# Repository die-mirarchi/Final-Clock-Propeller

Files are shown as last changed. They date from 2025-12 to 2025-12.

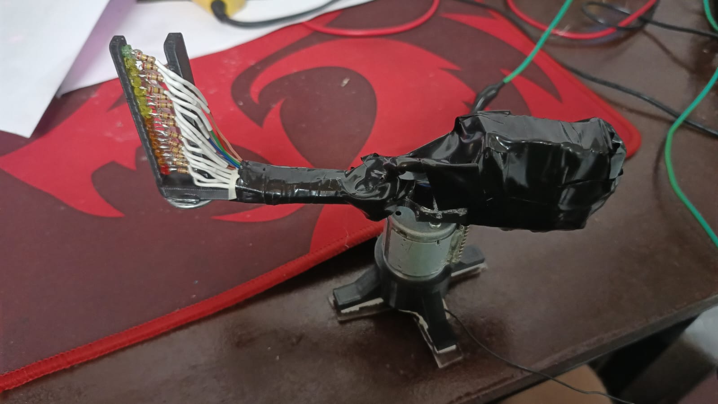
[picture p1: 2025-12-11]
docs/videos/photo1.jpeg

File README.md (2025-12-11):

# Digital Propeller 

## Descripción

Trabajo final para la materia **Digitales 2** de la **UNSAM** (Universidad Nacional de San Martín).  
**Año:** 2025 - Segundo Cuatrimestre  
**Autor:** Diego H. Mirarchi

Este proyecto implementa un digital propeller basado en el efecto de persistencia de visión (POV). Utiliza una barra vertical de 14 LEDs que, al girar, proyecta imágenes y texto en el aire mediante la sincronización precisa del encendido de los LEDs con la posición angular de rotación.

## Características Técnicas

- **Microcontrolador:** STM32F103 (Blue Pill)
- **LEDs:** 14 LEDs verticales controlados por GPIOA
- **Sincronización:** Detección por sensor hall SS49e con ADC de referencia en cada vuelta
- **Resolución angular:** 180 columnas por rotación completa (2° por columna)
- **Timer:** TIM2 configurado a 30 kHz para timestamping de rotación

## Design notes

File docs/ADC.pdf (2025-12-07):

# ADC - Analog to Digital Converter (Conversor Analógico Digital)

# Electrónica Digital II

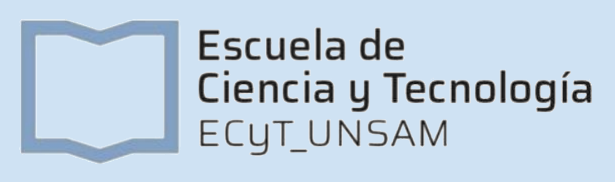
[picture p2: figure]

# ADC - Analog to Digital Converter

## ADC

## - Conversor de aproximaciones sucesivas de 12 bits

## - Canales: hasta 18, multiplexados (16 señales externas y 2 internas)

## - Modo de conversión: simple, continuo, scan o discontinuo

## - Almacena el resultado en un registro de 16 bits (alineado a izquierda o derecha)

## - Generación de interrupción al finalizar una conversión

## - El reloj ADCCLK es sincrónico con el APB2 clock. No puede superar los 14 MHz

Electrónica Digital II - ECyT

# Aproximaciones sucesivas (SAR)

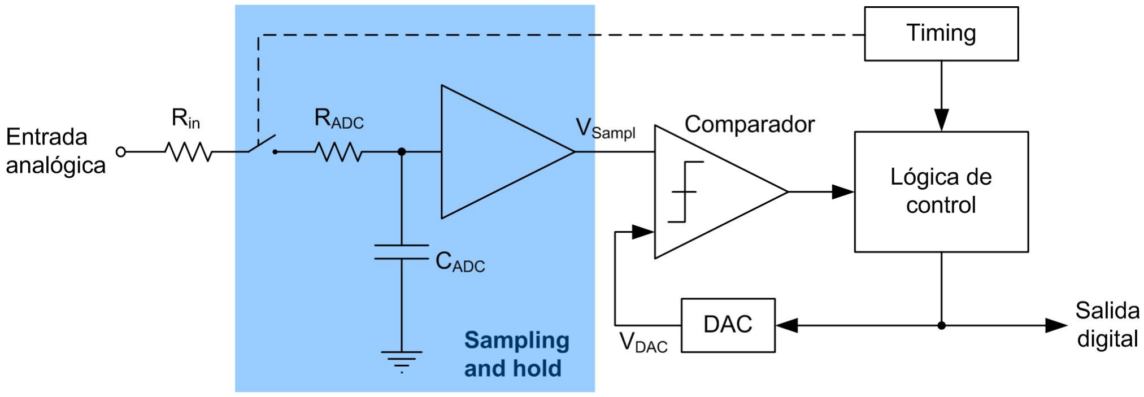
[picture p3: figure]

# Aproximaciones sucesivas (SAR)

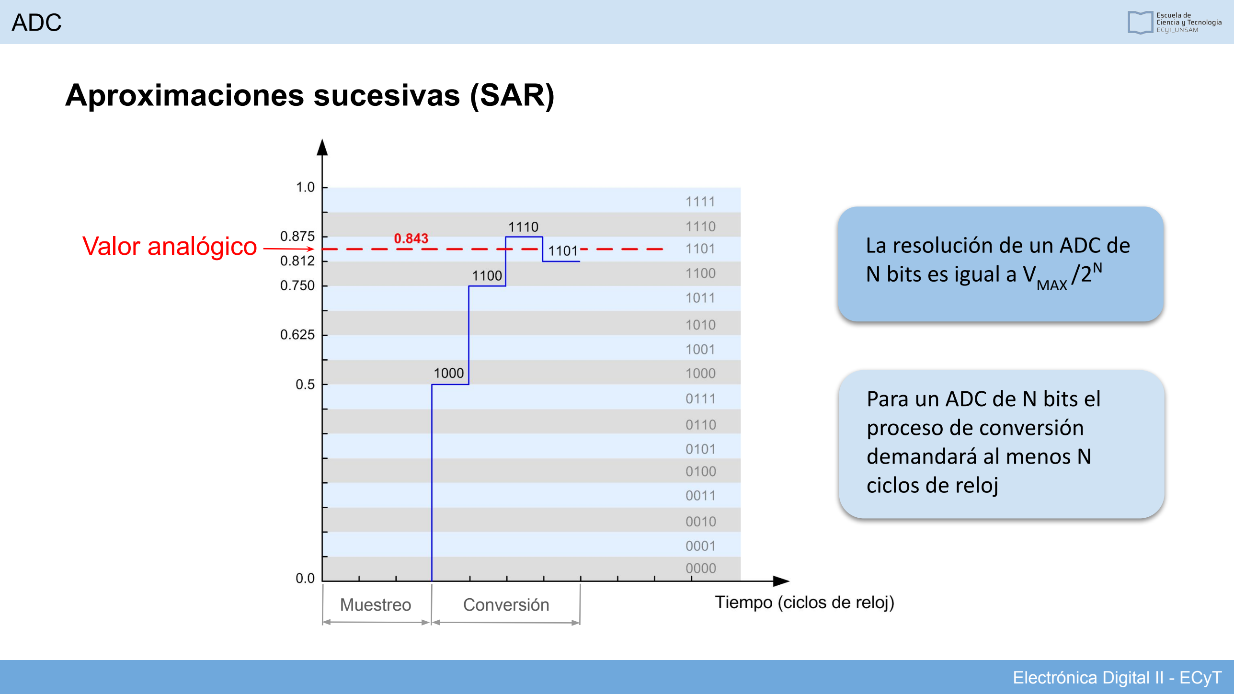
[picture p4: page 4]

Muestreo | Conversión

## La resolución de un ADC de N bits es igual a VMAX /2N

## Para un ADC de N bits el proceso de conversión demandará al menos N ciclos de reloj

## Valor analógico

# Tiempos de un ADC

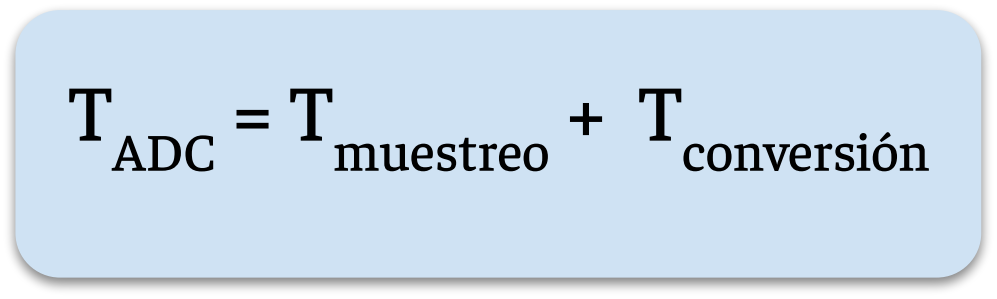
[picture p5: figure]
TADC = Tmuestreo + Tconversión

Suponiendo un ADC de 12 bits y tiempo de muestreo de 3 ciclos de reloj,

## con una frecuencia de operación de 10 MHz:

## TADC = Tmuestreo + Tconversión = 3 + 12 = 15 ciclos = 1.5 µs

# ADC - Analog to Digital Converter

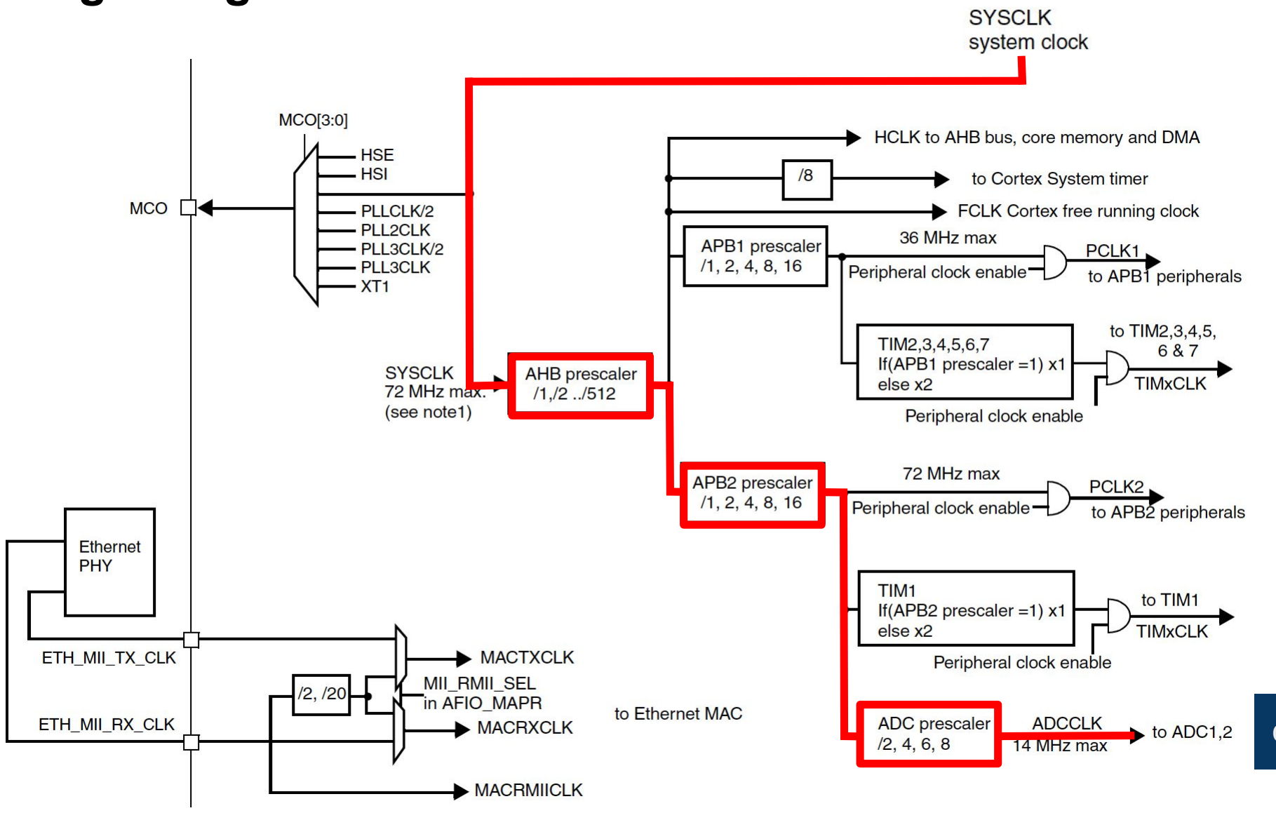
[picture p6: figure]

### clkADC ⩽ 14 MHz

# Selección de canal

## - Las conversiones pueden organizarse en dos grupos:

### - Compuesto por hasta 16 conversiones

### - Los canales regulares y su orden en la

### secuencia de conversión se seleccionan en el

### registro ADC_SQRx

### - La cantidad de conversiones debe ser escrita

### en los bits L[3:0] del registro ADC_SQR1

Grupo Regular | Grupo Inyectado

### - Compuesto por hasta 4 conversiones

### - Los canales inyectados y su orden en la

| secuencia de conversión se seleccionan en el registro ADC_JSQRx

### - La cantidad de conversiones debe ser escrita

| en los bits L[1:0] del registro ADC_JSQR

# Modo de conversión simple

## - El ADC sólo realiza una conversión

- La adquisición inicia colocando en ‘1’ el bit ADON en el registro ADC_CR2 (sólo para canal regular)

o por un trigger externo (para canal regular o inyectado).

## - Canal regular convertido:

## - El dato se guarda en el registro de 16 bits ADC_DR

- El flag EOC (End Of Conversion) se coloca en ‘1’ y la interrupción es generada si el bit

## EOCIE (EOC Interrupt Enable) está activo

## - Canal inyectado:

## - El dato se guarda en el registro de 16 bits ADC_DRJ1

- El flag JEOC (End Of Conversion Injected) se coloca en ‘1’ y la interrupción es generada si

## el bit JEOCIE está activo

## Finalmente el ADC se detiene

# Modo de conversión continua

## - El ADC inicia otra conversión apenas termina la actual

- La adquisición inicia colocando en ‘1’ el bit ADON en el registro ADC_CR2 (sólo para canal regular)

o por un trigger externo (para canal regular o inyectado).

## - Canal regular convertido:

## - El dato se guarda en el registro de 16 bits ADC_DR

- El flag EOC (End Of Conversion) se coloca en ‘1’ y la interrupción es generada si el bit

## EOCIE (EOC Interrupt Enable) está activo

## - Canal inyectado:

## - El dato se guarda en el registro de 16 bits ADC_DRJ1

- El flag JEOC (End Of Conversion Injected) se coloca en ‘1’ y la interrupción es generada si

## el bit JEOCIE está activo

# Modo Scan

## - Se adquiere un grupo de canales analógicos

- Se selecciona configurando el bit SCAN en el registro ADC_CR1.

## - Cuando se lo selecciona el ADC escanea todos los canales seleccionados en el registro

## ADC_SQRx (para canales regulares) o en el ADC_JSQR (para inyectados)

- Cada vez que finaliza una conversión continúa automáticamente con el siguiente canal del grupo.
- Al usar este modo el DMA debe estar activo ya que es usado para transferir los datos convertidos

de los canales de un grupo regular a la SRAM cada vez que se actualiza el registro ADC_DR.

- Los datos de los canales inyectados siempre se almacenan en los registro ADC_JDRx.

# Modos de operación

Canal único | Múltiples canales (Scan)

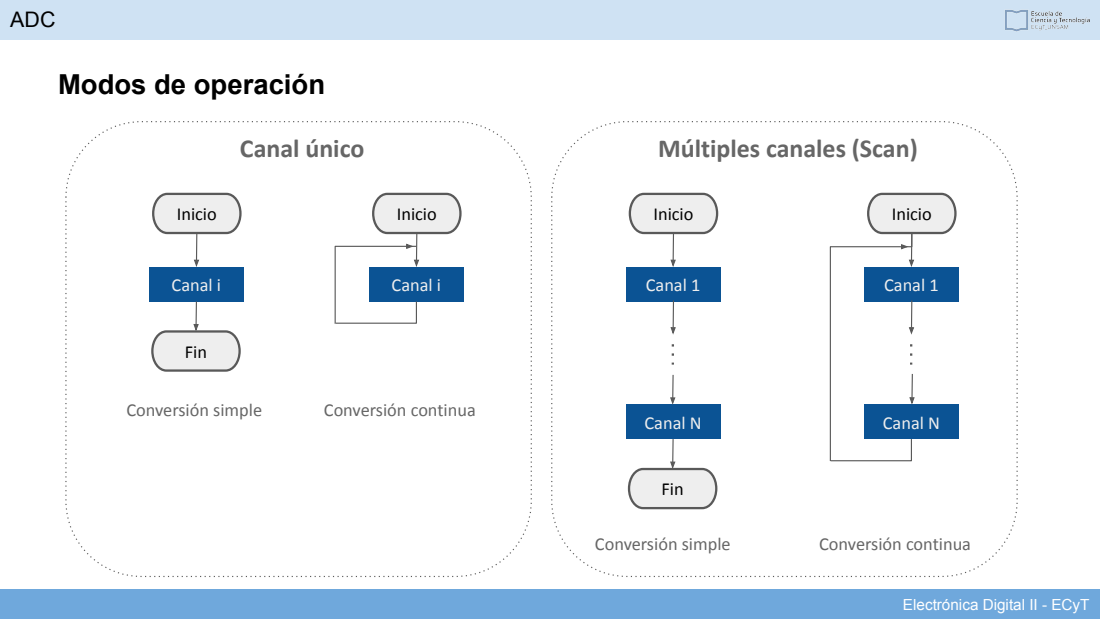
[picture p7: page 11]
Inicio; Fin; Canal i; Canal 1; Canal N; Conversión simple; Conversión continua

# Registros

## - Status Register (ADC_SR)

## - Control Register 1 / 2 (ADC_CR1 / ADC_CR2)

## - Sample Time Register 1 / 2 (ADC_SMPR1 / ADC_SMPR2)

## - Injected channel data offset register x (ADC_JOFRx) (x=1..4)

## - Regular sequence register 1 / 2 / 3 (ADC_SQR1 / ADC_SQR2 / ADC_SQR3)

## - Injected sequence register (ADC_JSQR)

## - Injected data register x (ADC_JDRx) (x= 1..4)

## - Regular data register (ADC_DR)

## - Watchdog high threshold register (ADC_HTR)

## - Watchdog low threshold register (ADC_LTR)

# ADC_SR (Registro de Estado)

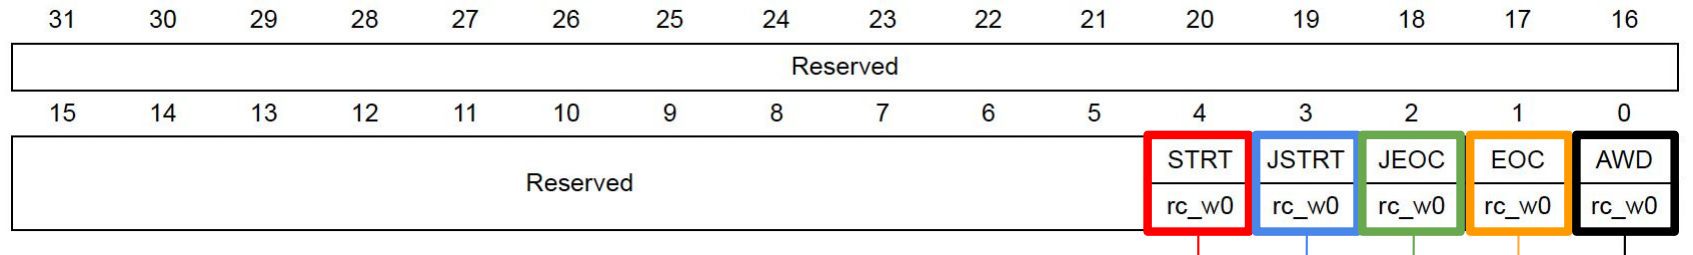
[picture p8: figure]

### Indica el inicio de la conversión de un canal regular

### Indica el inicio de la conversión de un grupo de canal inyectado

### Indica el final de la conversión de un canal inyectado

### Indica el final de la conversión (canal inyectado o regular)

### Indica si el valor convertido es mayor o menor a lo configurado

# ADC_CR1 (Registro de Control 1)

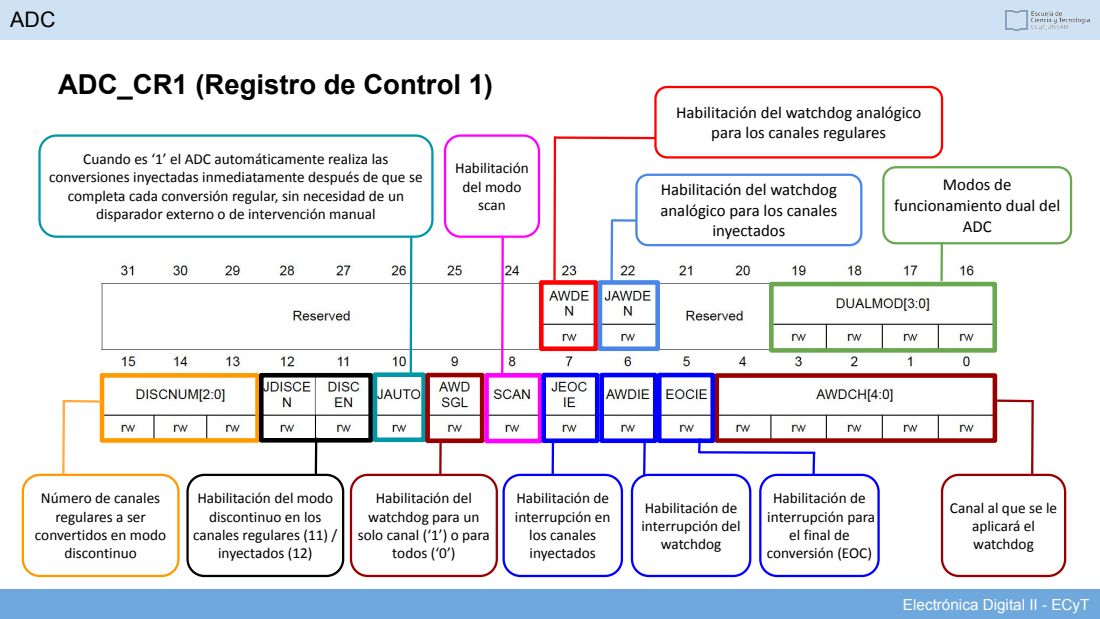
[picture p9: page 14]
inyectados; Modos de; ADC; Habilitación del modo scan; Habilitación de interrupción en los canales inyectados; Habilitación de interrupción del watchdog

Habilitación del watchdog analógico
para los canales regulares

Cuando es ‘1’ el ADC automáticamente realiza las
conversiones inyectadas inmediatamente después de que se
completa cada conversión regular, sin necesidad de un
disparador externo o de intervención manual

Habilitación del watchdog
analógico para los canales

funcionamiento dual del

Número de canales
regulares a ser
convertidos en modo
discontinuo

Habilitación del modo
discontinuo en los
canales regulares (11) /
inyectados (12)

Habilitación del
watchdog para un
solo canal (‘1’) o para
todos (‘0’)

Habilitación de
interrupción para
el final de
conversión (EOC)

Canal al que se le
aplicará el
watchdog

# ADC_CR2 (Registro de Control 2)

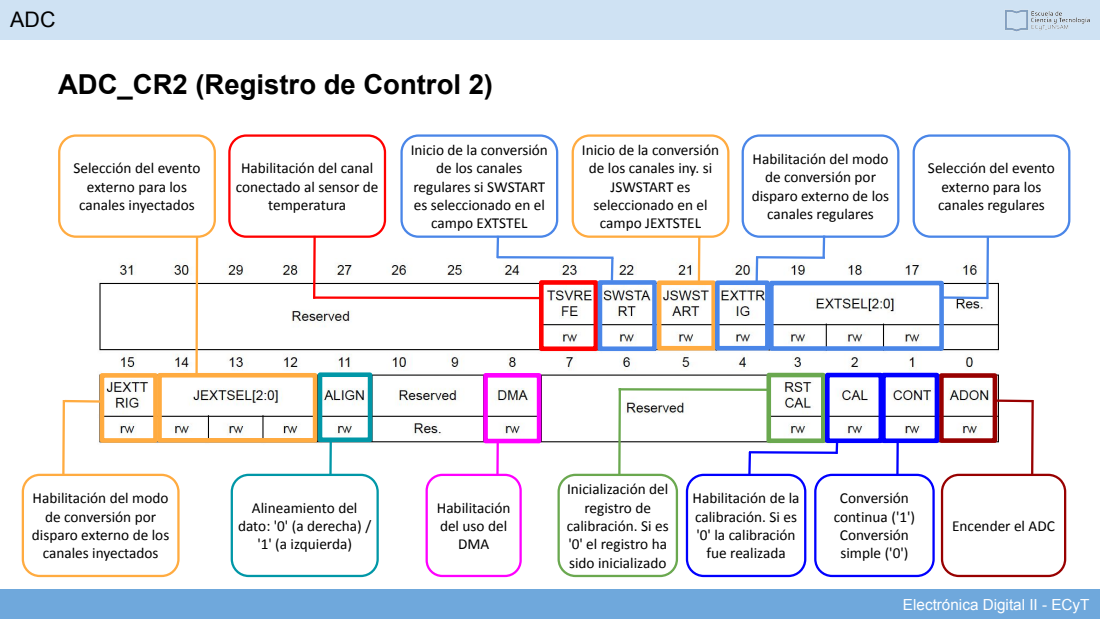
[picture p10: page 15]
Conversión continua ('1') Conversión simple ('0'); Alineamiento del dato: '0' (a derecha) / '1' (a izquierda)

Inicio de la conversión
de los canales
regulares si SWSTART
es seleccionado en el
campo EXTSTEL

de los canales iny. si
JSWSTART es
seleccionado en el
campo JEXTSTEL

Habilitación del modo
de conversión por
disparo externo de los
canales regulares

Selección del evento
externo para los
canales inyectados

Habilitación del canal
conectado al sensor de
temperatura

Inicialización del
registro de
calibración. Si es
'0' el registro ha
sido inicializado

Habilitación de la
'0' la calibración
fue realizada

Habilitación
del uso del
DMA

Encender el ADC

# ADC_SMPR1 (Registro de Tiempo de Muestreo 1)

## 000: 1.5 ciclos 100: 41.5 ciclos

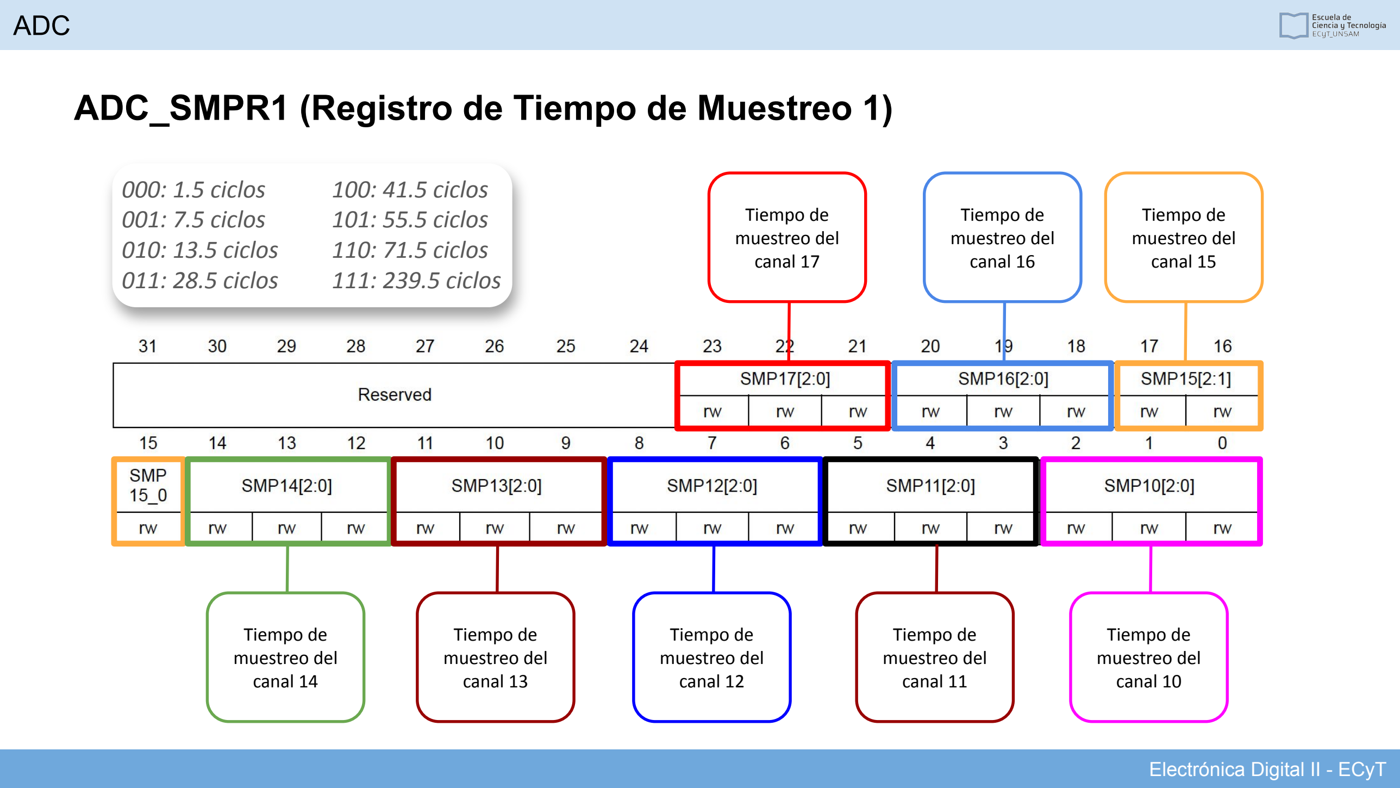
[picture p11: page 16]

Tiempo de
muestreo del
canal 13

Tiempo de
muestreo del
canal 12

Tiempo de
muestreo del
canal 11

Tiempo de
muestreo del
canal 10

Tiempo de
muestreo del
canal 14

Tiempo de
muestreo del
canal 17

Tiempo de
muestreo del
canal 16

Tiempo de
muestreo del
canal 15
001: 7.5 ciclos | 101: 55.5 ciclos
010: 13.5 ciclos | 110: 71.5 ciclos
011: 28.5 ciclos | 111: 239.5 ciclos

# ADC_SMPR2 (Registro de Tiempo de Muestreo 2)

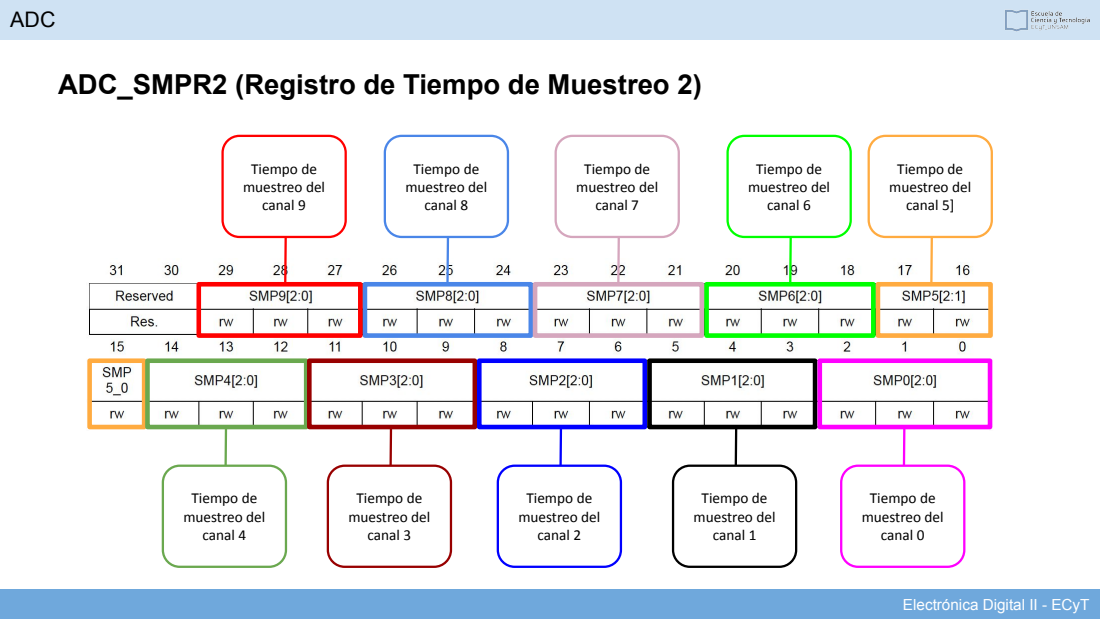
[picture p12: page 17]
Tiempo de muestreo del canal 3; Tiempo de muestreo del canal 2; Tiempo de muestreo del canal 1; Tiempo de muestreo del canal 0; Tiempo de muestreo del canal 4; Tiempo de muestreo del canal 9; Tiempo de muestreo del canal 8; Tiempo de muestreo del canal 5]; Tiempo de muestreo del canal 7; Tiempo de muestreo del canal 6

# ADC_JOFRx (Registro de Offset de dato de canal inyectado)

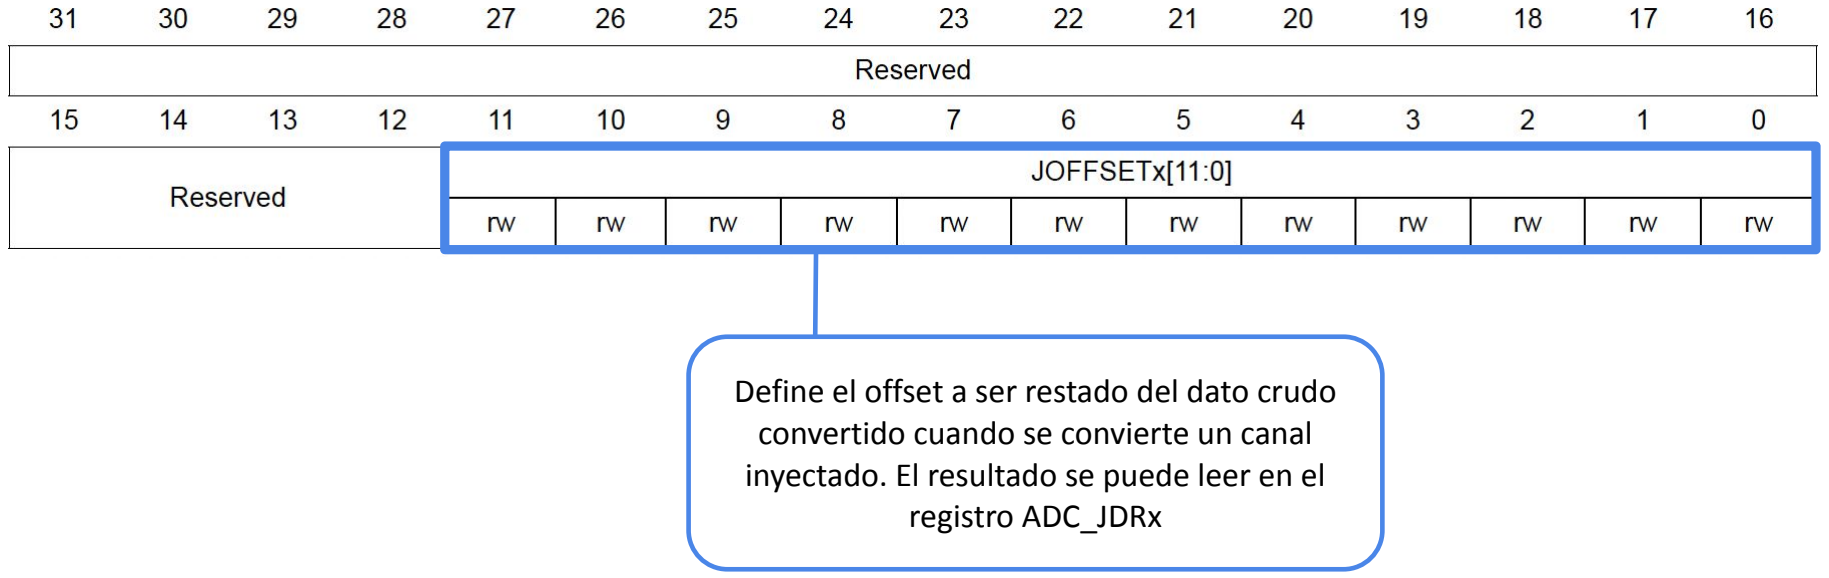
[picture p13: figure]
convertido cuando se convierte un canal; registro ADC_JDRx

Define el offset a ser restado del dato crudo

inyectado. El resultado se puede leer en el

# ADC_HTR (Registro para el umbral alto del watchdog)

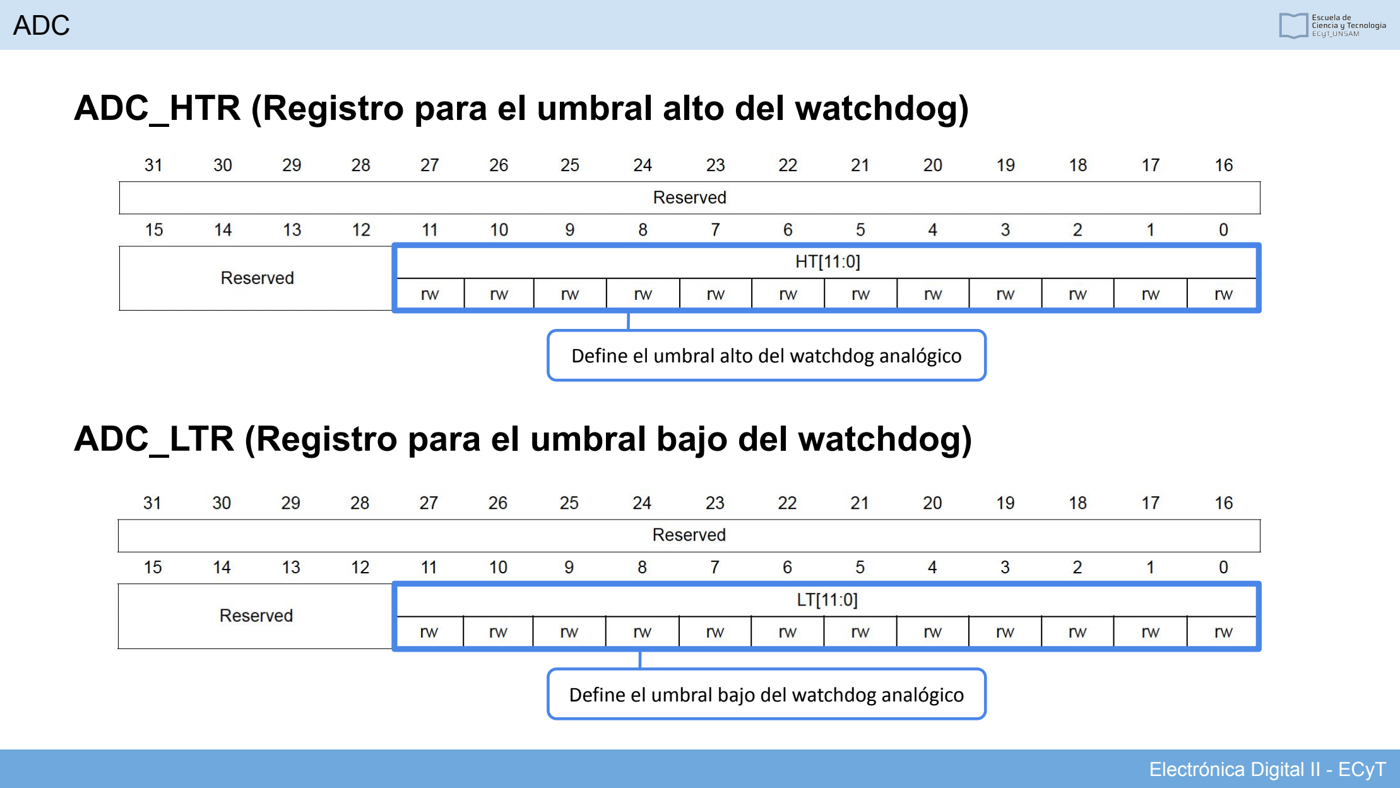
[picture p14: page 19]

Define el umbral alto del watchdog analógico

# ADC_LTR (Registro para el umbral bajo del watchdog)

Define el umbral bajo del watchdog analógico

# ADC_SQR1 (Registro de secuencia de los canales regulares 1)

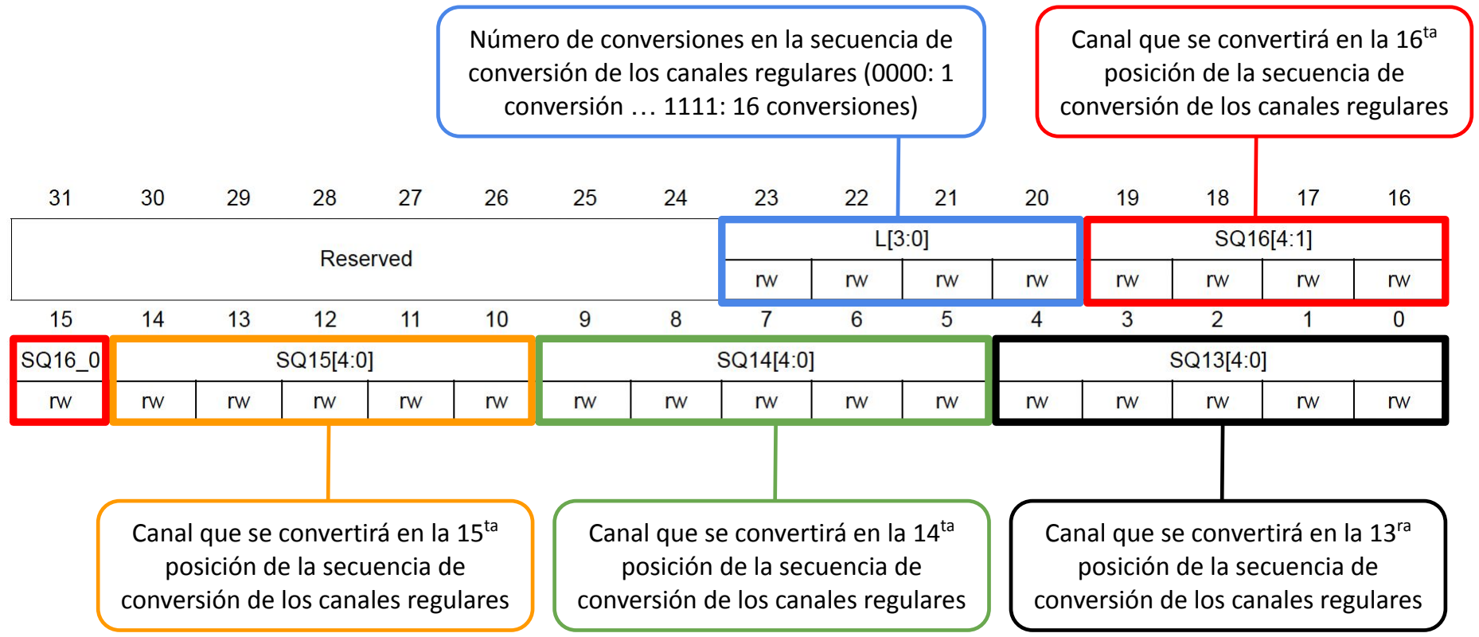
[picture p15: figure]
conversión … 1111: 16 conversiones); Canal que se convertirá en la 16ta posición de la secuencia de conversión de los canales regulares; Canal que se convertirá en la 15ta posición de la secuencia de conversión de los canales regulares; Canal que se convertirá en la 14ta posición de la secuencia de conversión de los canales regulares; Canal que se convertirá en la 13ra posición de la secuencia de conversión de los canales regulares

Número de conversiones en la secuencia de conversión de los canales regulares (0000: 1

# ADC_SQR2 (Registro de secuencia de los canales regulares 2)

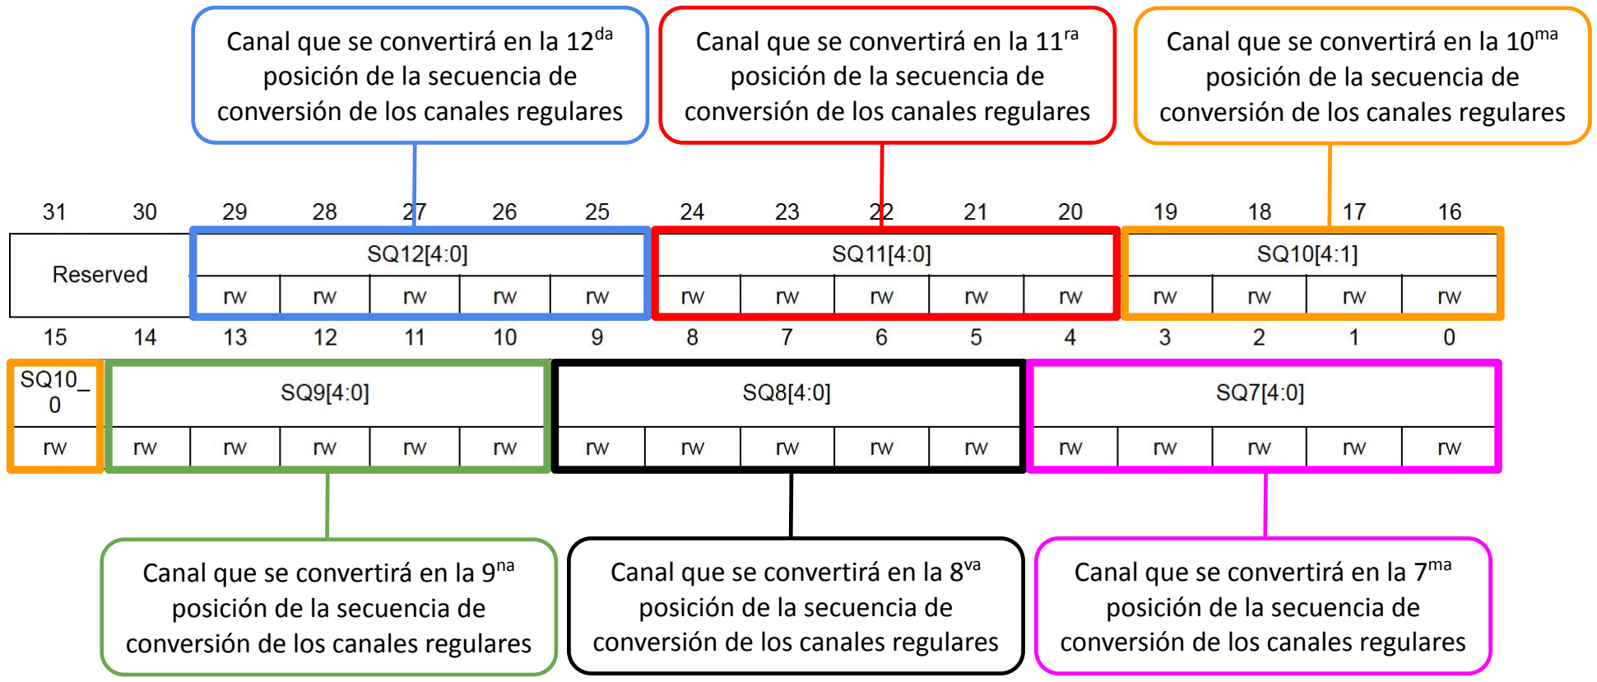
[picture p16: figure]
Canal que se convertirá en la 11ra posición de la secuencia de conversión de los canales regulares; Canal que se convertirá en la 10ma posición de la secuencia de conversión de los canales regulares; Canal que se convertirá en la 9na posición de la secuencia de conversión de los canales regulares; Canal que se convertirá en la 8va posición de la secuencia de conversión de los canales regulares; Canal que se convertirá en la 12da posición de la secuencia de conversión de los canales regulares; Canal que se convertirá en la 7ma posición de la secuencia de conversión de los canales regulares

# ADC_SQR3 (Registro de secuencia de los canales regulares 3)

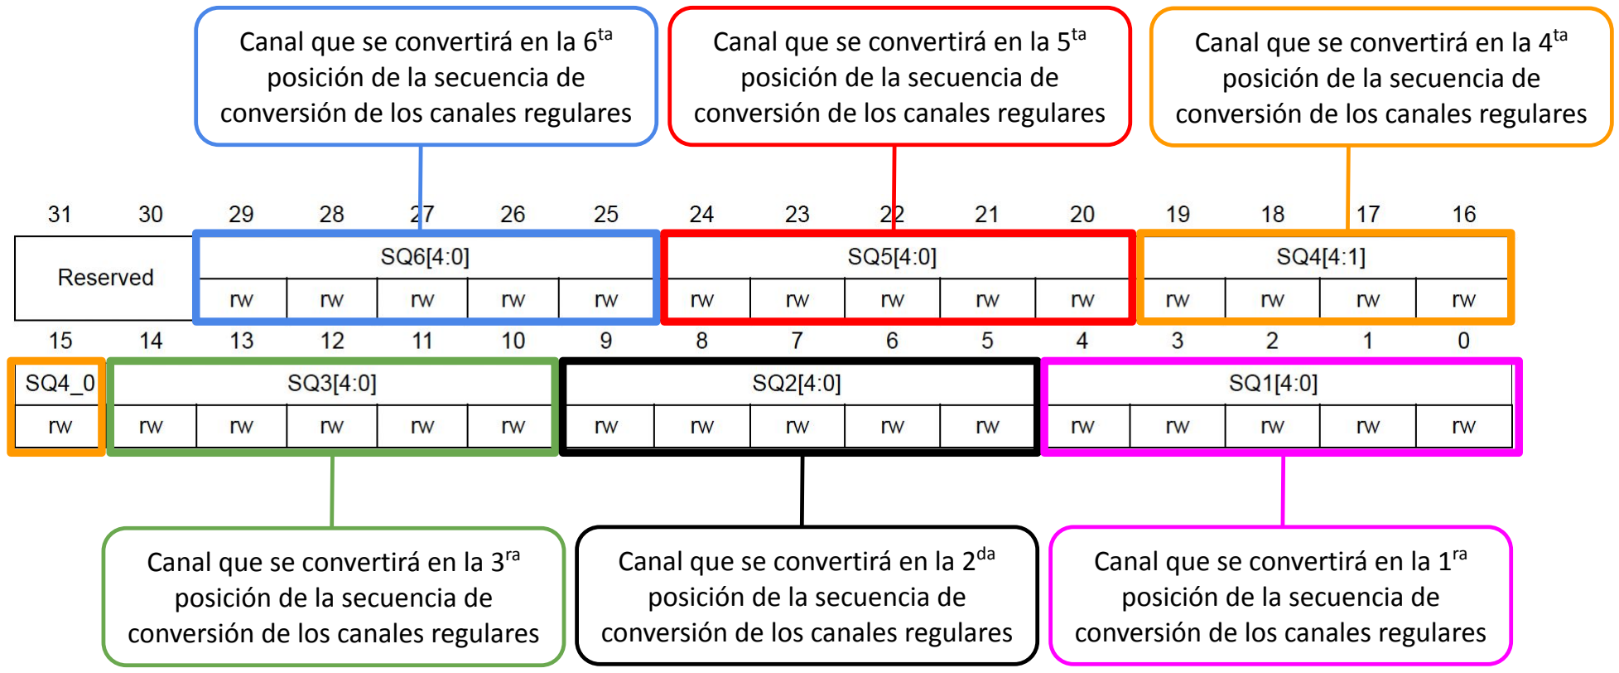
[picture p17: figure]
Canal que se convertirá en la 5ta posición de la secuencia de conversión de los canales regulares; Canal que se convertirá en la 4ta posición de la secuencia de conversión de los canales regulares; Canal que se convertirá en la 3ra posición de la secuencia de conversión de los canales regulares; Canal que se convertirá en la 2da posición de la secuencia de conversión de los canales regulares; Canal que se convertirá en la 6ta posición de la secuencia de conversión de los canales regulares; Canal que se convertirá en la 1ra posición de la secuencia de conversión de los canales regulares

# ADC_JSQR (Registro de secuencia de los canales inyectados)

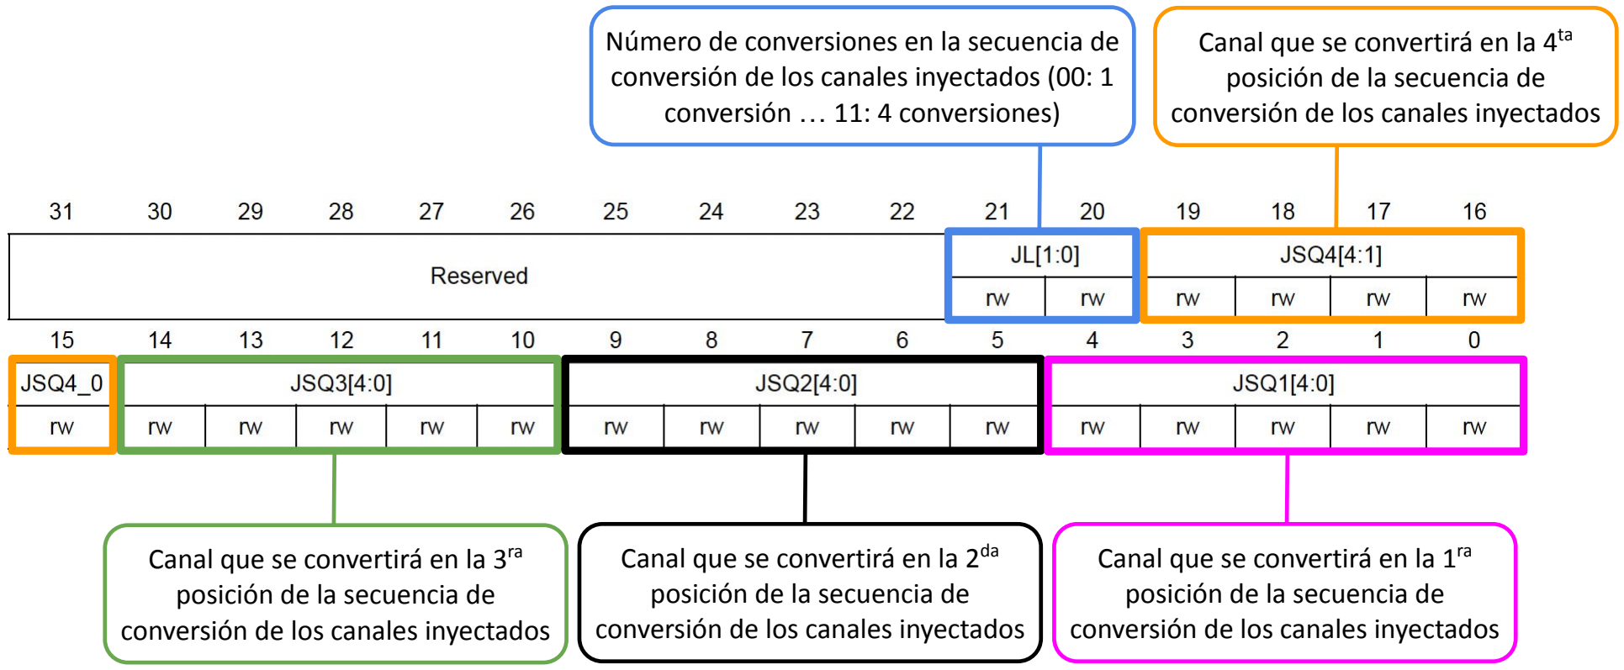
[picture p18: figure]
Canal que se convertirá en la 4ta posición de la secuencia de conversión de los canales inyectados; Canal que se convertirá en la 3ra posición de la secuencia de conversión de los canales inyectados; Canal que se convertirá en la 2da posición de la secuencia de conversión de los canales inyectados; conversión … 11: 4 conversiones); Canal que se convertirá en la 1ra posición de la secuencia de conversión de los canales inyectados

Número de conversiones en la secuencia de conversión de los canales inyectados (00: 1

# ADC_JSQR (Registro de secuencia de los canales inyectados)

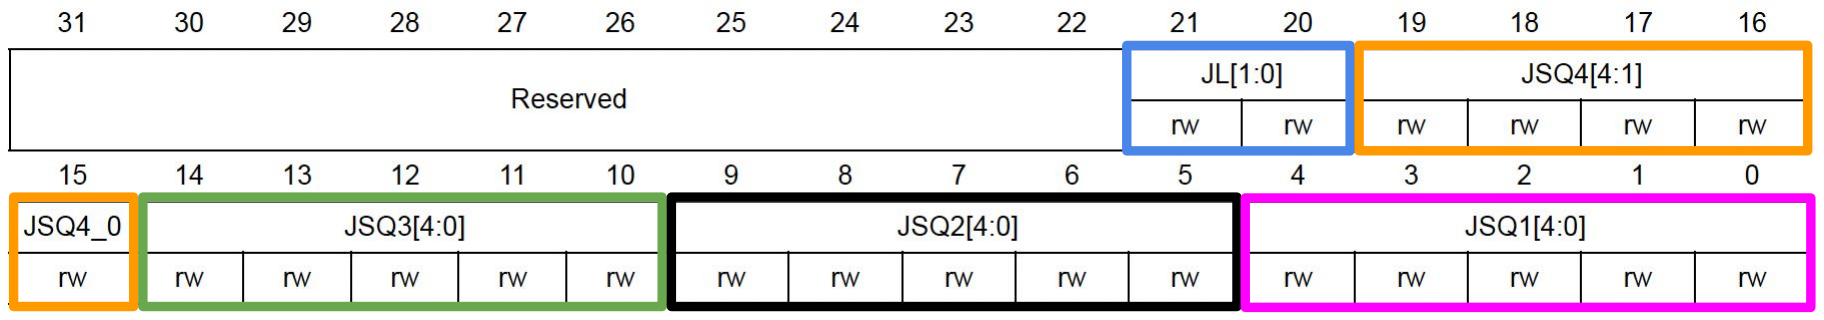
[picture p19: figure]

Cuando JL=3 (4 conversiones en la secuencia), el ADC convierte los canales en el orden: JSQ1[4:0] → JSQ2[4:0] → JSQ3[4:0] → JSQ4[4:0]

Cuando JL=2 (3 conversiones en la secuencia), el ADC convierte los canales en el orden: JSQ2[4:0] → JSQ3[4:0] → JSQ4[4:0]

Cuando JL=1 (2 conversiones en la secuencia), el ADC convierte los canales en el orden: JSQ3[4:0] → JSQ4[4:0]

Cuando JL=0 (1 conversión en la secuencia), el ADC convierte sólo el canal JSQ4[4:0]

# ADC_JDRx (Registro de datos de los canales inyectados) (x = 1..4)

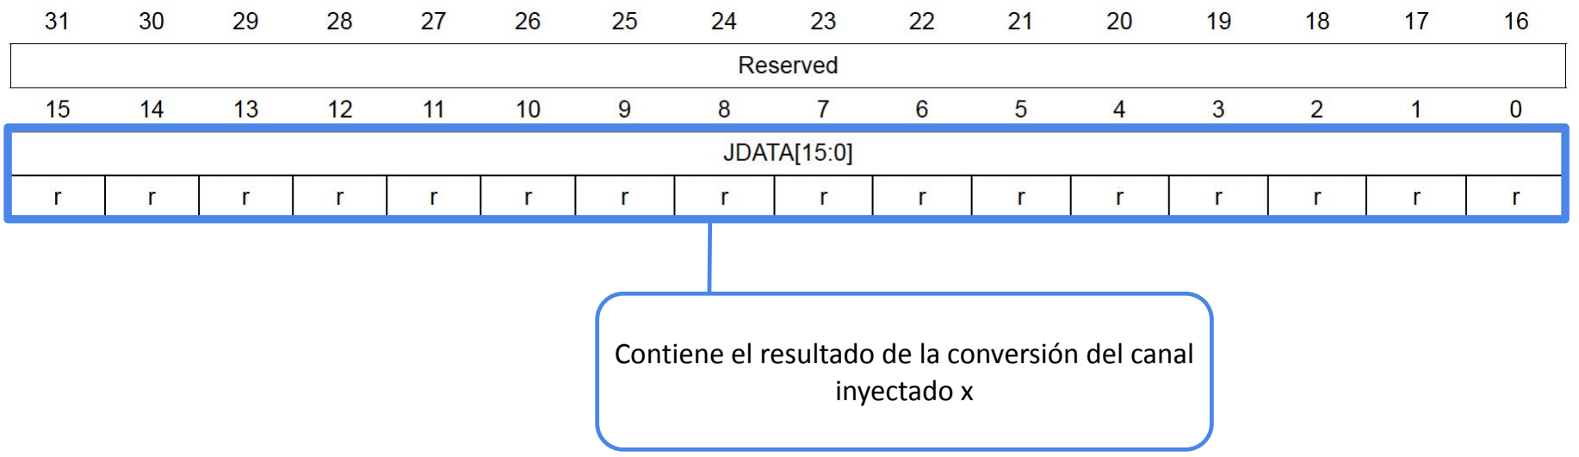
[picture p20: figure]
inyectado x

Contiene el resultado de la conversión del canal

# ADC_DR (Registro de datos de los canales regulares)

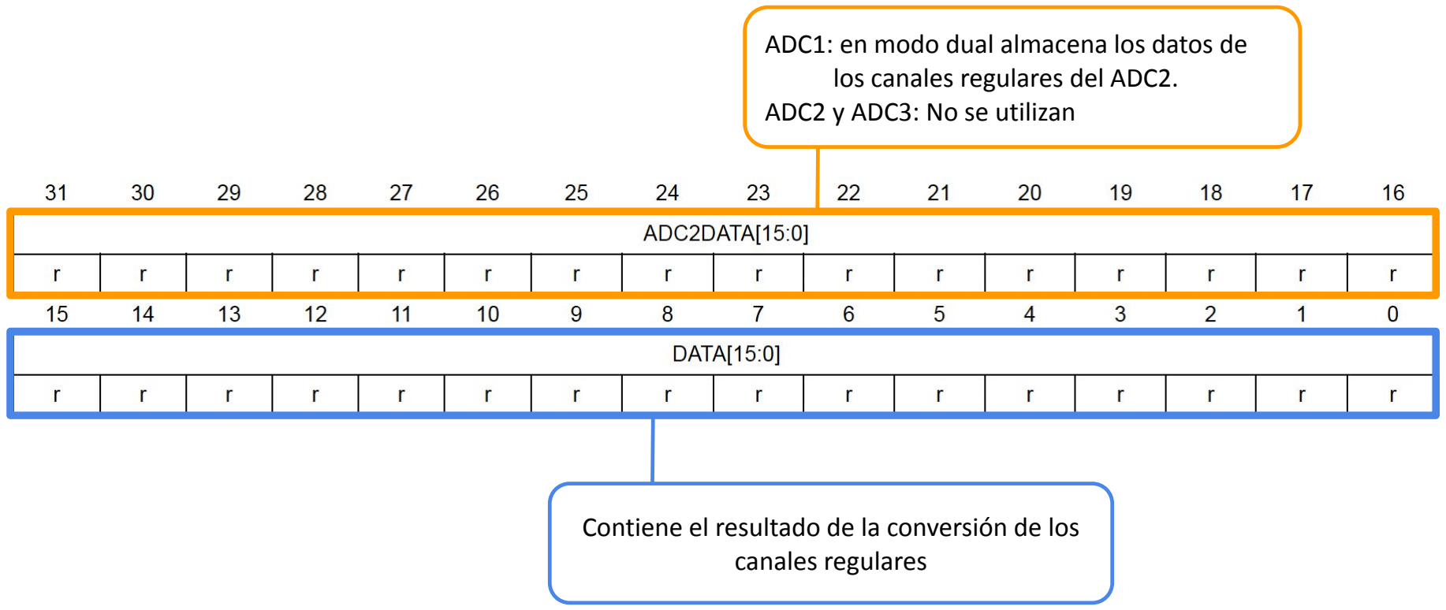
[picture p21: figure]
canales regulares; los canales regulares del ADC2. ADC2 y ADC3: No se utilizan

Contiene el resultado de la conversión de los

ADC1: en modo dual almacena los datos de

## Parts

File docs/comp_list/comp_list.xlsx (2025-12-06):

Componente | Cantidad
ULN2003 | 2
Leds | 14
BluePill | 1
Resistor | 14
Bateria 3.7V | 1
A3144 | 1
TP4056 | 1
Step-Up DC DC | 1
Motor DC | 1
Iman | 1

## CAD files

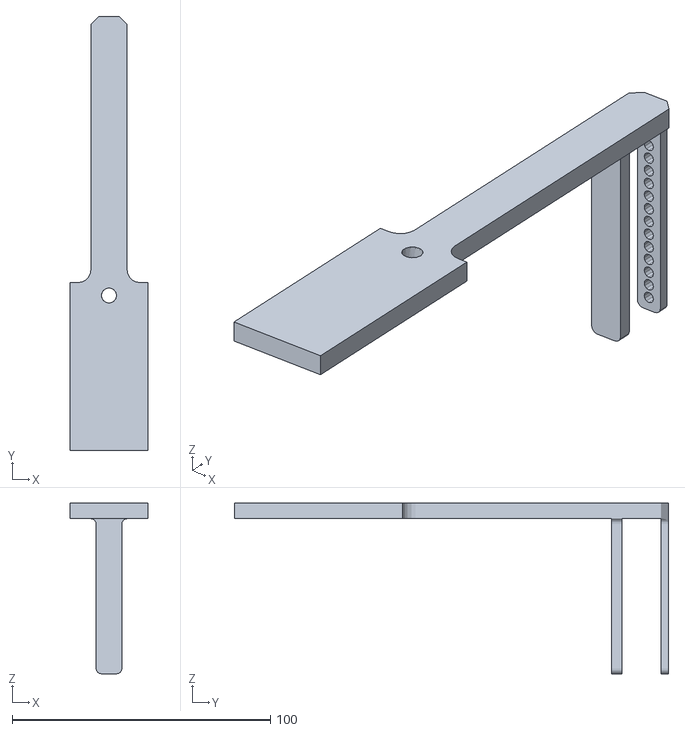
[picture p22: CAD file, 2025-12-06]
3d/leds_holder.stl
30.0 x 168.0 x 66.0

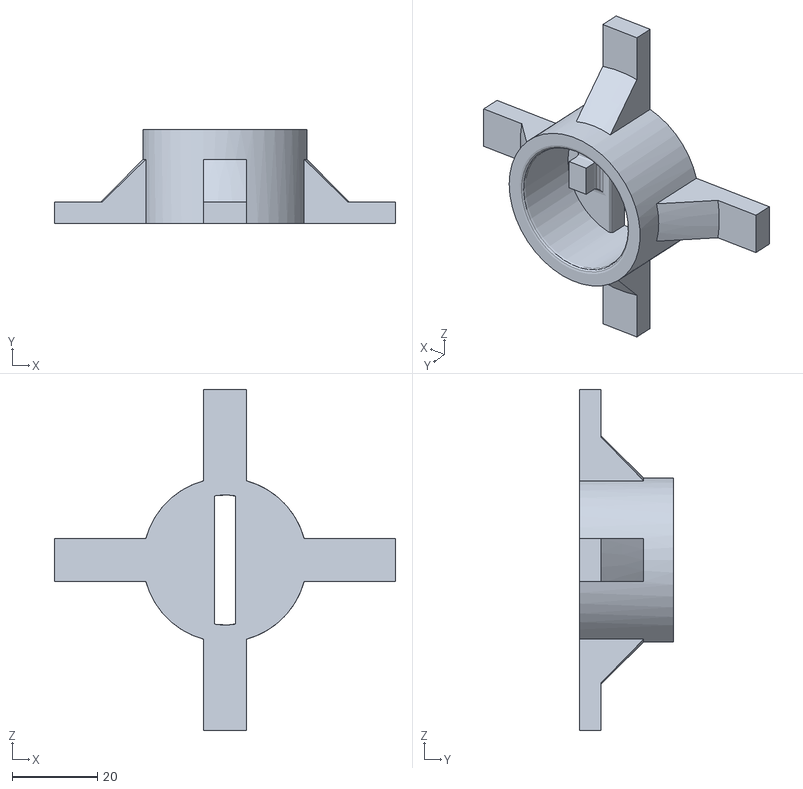
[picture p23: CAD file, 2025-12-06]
3d/motor_holder.stl
80.0 x 22.0 x 80.0

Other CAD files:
3d/OldVersions/leds_holder.0002.ipt
3d/Part1.ipt
3d/cnc_wood_holder.ipt
3d/leds_holder - copia.ipt
3d/leds_holder.ipt

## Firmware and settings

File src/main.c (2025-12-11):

#define SRAM_SIZE		((uint32_t) 0x00005000)
#define SRAM_BASE		((uint32_t) 0x20000000)
#define STACKINIT		((interrupt_t)(SRAM_BASE+SRAM_SIZE))

typedef int			   int32_t;
typedef short		   int16_t;
typedef char		   int8_t;
typedef unsigned int   uint32_t;
typedef unsigned short uint16_t;
typedef unsigned char  uint8_t;
typedef unsigned long long uint64_t;

typedef void(*interrupt_t)(void);

typedef union {
	uint8_t  byte[4];
	uint16_t hword[2];
	uint32_t word;
} word_t;

typedef word_t page[0x400/sizeof(uint32_t)];

// Memory map

enum {TIM2	= 0, TIM3  = 1, TIM4  = 2 };
enum {GPIOA = 0, GPIOB = 1, GPIOC = 2, GPIOD = 3, GPIOE = 4, GPIOF = 5 };
enum {DMA1	= 0 };
enum {CHN1	= 0, CHN2  = 1, CHN3  = 2, CHN4  = 3, CHN5	= 4, CHN6  = 5, CHN7 = 6, CHN8 = 7 };
enum {ADC1	= 0 };
struct {
	union {
		struct {
			uint32_t CR1;
			uint32_t CR2;
			uint32_t SMCR;
			uint32_t DIER;
			uint32_t SR;
			uint32_t EGR;
			uint32_t CCMR1;
			uint32_t CCMR2;
			uint32_t CCER;
			uint32_t CNT;
			uint32_t PSC;
			uint32_t ARR;
			uint32_t RES1;
			uint32_t CCR1;
			uint32_t CCR2;
			uint32_t CCR3;
			uint32_t CCR4;
			uint32_t BDTR;
			uint32_t DCR;
			uint32_t DMAR;
		} REGs;
		page reserved;
	} TIMs[3];

	word_t reserved1[(0x40002800-0x40000c00)/sizeof(word_t)];
	page RTC;
	page WWDG;
	page IWDG;
	word_t reserved2[(0x40003800-0x40003400)/sizeof(word_t)];
	page SPI2;
	word_t reserved3[(0x40004400-0x40003c00)/sizeof(word_t)];
	page USART[2];
	word_t reserved4[(0x40005400-0x40004c00)/sizeof(word_t)];
	page I2C[2];
	page USB;
	page USBCAN_SRAM;
	page bxCAN;
	word_t reserved5[(0x40006c00-0x40006800)/sizeof(word_t)];
	page BKP;
	page PWR;
	word_t reserved6[(0x40010000-0x40007400)/sizeof(word_t)];

	page AFIO;
	page EXTI;

	union {
		struct {
			uint32_t CRL;
			uint32_t CRH;
			uint32_t IDR;
			uint32_t ODR;
			uint32_t BSRR;
			uint32_t BRR;
			uint32_t LCKR;
		} REGs;
		page reserved;
	} GPIOs[5];
	word_t reserved7[(0x40012400-0x40011C00)/sizeof(word_t)];
union {
    struct {
        uint32_t SR;
        uint32_t CR1;
        uint32_t CR2;
        uint32_t SMPR1;
        uint32_t SMPR2;
        uint32_t JOFR[4];   // JOFR1..4
        uint32_t HTR;
        uint32_t LTR;
        uint32_t SQR1;
        uint32_t SQR2;
        uint32_t SQR3;
        uint32_t JSQR;
        uint32_t JDR[4];    // JDR1..4
        uint32_t DR;
    } REGs;
    page reserved;
} ADC[2];
	page TIM1;
	page SPI1;
	word_t reserved8[(0x40013800-0x40013400)/sizeof(word_t)];
	union  {
		struct {
			uint32_t SR;
			uint32_t DR;
			uint32_t BRR;
			uint32_t CR1;
			uint32_t CR2;
			uint32_t CR3;
			uint32_t GTPR;
		} REGs;
		page reserved;
	} USART1;
	word_t reserved9[(0x40020000-0x40013C00)/sizeof(word_t)];
	union {
		struct {
			uint32_t ISR;
			uint32_t IFCR;
			struct {
				uint32_t CCR;
				uint32_t CNDTR;
				uint32_t CPAR;
				uint32_t CMAR;
				uint32_t RESERVED;
			} CHN[8];
		} REGs;
		page reserved;
	} DMAs[1];
	word_t reservedA[(0x40021000-0x40020400)/sizeof(word_t)];

	union {
		struct {
			uint32_t CR;
			uint32_t CFGR;
			uint32_t CIR;
			uint32_t APB2RSTR;
			uint32_t APB1RSTR;
			uint32_t AHBENR;
			uint32_t APB2ENR;
			uint32_t APB1ENR;
			uint32_t BDCR;
			uint32_t CSR;
			uint32_t AHBRSTR;
			uint32_t CFGR2;
		} REGs;
		page reserved;
	} RCC;
	word_t reservedB[(0x40022000-0x40021400)/sizeof(word_t)];

	union {
		struct {
			uint32_t ACR;
			uint32_t KEYR;
			uint32_t OPTKEYR;
			uint32_t SR;
			uint32_t CR;
			uint32_t AR;
			uint32_t reserved;
			uint32_t OBR;
			uint32_t WRPR;
		} REGs;
		page reserved;
	} FLASH;
} volatile *const DEVMAP = (void *) 0x40000000;

#define ENA_IRQ(IRQ) {CTX->NVIC.REGs.ISER[((uint32_t)(IRQ) >> 5)] = (1 << ((uint32_t)(IRQ) & 0x1F));}
#define DIS_IRQ(IRQ) {CTX->NVIC.REGs.ICER[((uint32_t)(IRQ) >> 5)] = (1 << ((uint32_t)(IRQ) & 0x1F));}
#define CLR_IRQ(IRQ) {CTX->NVIC.REGs.ICPR[((uint32_t)(IRQ) >> 5)] = (1 << ((uint32_t)(IRQ) & 0x1F));}

struct {
	word_t reversed0[(0xe000e010-0xe0000000)/sizeof(word_t)];
	union {
		struct {
			uint32_t CSR;
			uint32_t RVR;
			uint32_t CVR;
			uint32_t CALIB;
		} REGs;
	} SYSTICK;
	word_t reversed1[(0xe000e100-0xe000e020)/sizeof(word_t)];
	union {
		struct {
			uint32_t ISER[8];
			uint32_t RES0[24];
			uint32_t ICER[8];
			uint32_t RES1[24];
			uint32_t ISPR[8];
			uint32_t RES2[24];
			uint32_t ICPR[8];
			uint32_t RES3[24];
			uint32_t IABR[8];
			uint32_t RES4[56];
			uint8_t  IPR[240];
			uint32_t RES5[644];
			uint32_t STIR;
		} REGs;
	} NVIC;
} volatile *const CTX = ((void *) 0xE0000000);

enum IRQs {
	IRQ_DMA1CHN2  = 12,
	IRQ_ADC1_2	  = 18,
	IRQ_TIM2	  = 28,
	IRQ_USART1	  = 37,
	IRQ_EXTI15_10 = 40,
};

#define LED_PATTERN_LENGTH            180U
#define ADC_THRESHOLD_LOW_RAW         1365U  // ~1100mV
#define ADC_THRESHOLD_HIGH_RAW        1870U  // ~1500mV
#define ADC_CHANNEL_B1                9U
#define ADC_SAMPLE_TIME_CYCLES        0b111
#define GPIO_OUTPUT_MODE_PUSH_PULL    0x33333333
#define TIM2_PRESCALER_30KHZ          (2400U - 1U)
#define TIM2_AUTO_RELOAD_MAX_16BIT    0xFFFFU

static volatile uint8_t low_detected = 0;
static volatile uint32_t delta_ticks = 1;
static volatile uint16_t laps = 0;

static const uint16_t led_pattern[180] = {
        0x8080, 0x8080, 0x8080, 0x8080, 0x9FFF, 0x90C0, 0x90C0, 0x90C0,
        0x90C0, 0x88A0, 0x879F, 0x8080, 0x8080, 0x9FEF, 0x8080, 0x8080,
        0x879F, 0x88A0, 0x90C0, 0x91C0, 0x91C0, 0x89C0, 0x87A0, 0x8080,
        0x8080, 0x9FEF, 0x8080, 0x8080, 0x80C0, 0x80C0, 0x80C0, 0x9FFF,
        0x80C0, 0x80C0, 0x80C0, 0x8080, 0x8080, 0x9C80, 0x8381, 0x829E,
        0x82E0, 0x829E, 0x8381, 0x9C80, 0x8080, 0x8080, 0x9FFF, 0x9080,
        0x9080, 0x9080, 0x9080, 0x9080, 0x8080, 0x8080, 0x9FFF, 0x90C2,
        0x90C2, 0x90C0, 0x90C0, 0x90C0, 0x8080, 0x8080, 0x889C, 0x90A2,
        0x90C2, 0x90C1, 0x90C1, 0x90C1, 0x8FA0, 0x8080, 0x8080, 0x8080,
        0x90C0, 0x90C0, 0x9FFF, 0x90C0, 0x90C0, 0x8080, 0x8080, 0x90C0,
        0x90C0, 0x9FFF, 0x90C0, 0x90C0, 0x8080, 0x8080, 0x8080, 0x0000,
        0x0000, 0x0000, 0x8082, 0x8082, 0x8085, 0x8085, 0x8188, 0x8188,
        0x8290, 0x8290, 0x84A0, 0x84A0, 0x98C0, 0x98C0, 0x84A0, 0x84A0,
        0x8290, 0x8290, 0x8188, 0x8188, 0x8085, 0x8085, 0x8082, 0x8082,
        0x0000, 0x0000, 0x8080, 0x8080, 0x8080, 0x9FFF, 0x80A0, 0x8090,
        0x8088, 0x8090, 0x80A0, 0x9FFF, 0x8080, 0x8080, 0x9FEF, 0x8080,
        0x8080, 0x9FFF, 0x80C1, 0x81C1, 0x82C1, 0x84C2, 0x98BC, 0x8080,
        0x8080, 0x9C80, 0x8381, 0x828E, 0x82B8, 0x82C0, 0x82B8, 0x828E,
        0x8381, 0x9C80, 0x8080, 0x8080, 0x9FFF, 0x80C1, 0x81C1, 0x82C1,
        0x84C2, 0x98BC, 0x8080, 0x8080, 0x879F, 0x88A0, 0x90C0, 0x90C0,
        0x90C0, 0x90C0, 0x8080, 0x8080, 0x9FFF, 0x8180, 0x8180, 0x8180,
        0x8180, 0x8180, 0x9FFF, 0x8080, 0x8080, 0x9FEF, 0x8080, 0x8080,
        0x8080, 0x8080, 0x8080, 0x8080
};


void ADC1_2_IRQHandler(void);
int  main(void);

const interrupt_t vector_table[] __attribute__ ((section(".vtab"))) = {
	STACKINIT,												// 0x0000_0000 Stack Pointer
	(interrupt_t) main,										// 0x0000_0004 Reset
	0,														// 0x0000_0008
	0,														// 0x0000_000C
	0,														// 0x0000_0010
	0,														// 0x0000_0014
	0,														// 0x0000_0018
	0,														// 0x0000_001C
	0,														// 0x0000_0020
	0,														// 0x0000_0024
	0,														// 0x0000_0028
	0,														// 0x0000_002C
	0,														// 0x0000_0030
	0,														// 0x0000_0034
	0,														// 0x0000_0038
	0,														// 0x0000_003C SYSTICK
	0,														// 0x0000_0040
	0,														// 0x0000_0044
	0,														// 0x0000_0048
	0,														// 0x0000_004C
	0,														// 0x0000_0050
	0,														// 0x0000_0054
	0,														// 0x0000_0058
	0,														// 0x0000_005C
	0,														// 0x0000_0060
	0,														// 0x0000_0064
	0,														// 0x0000_0068
	0,														// 0x0000_006C
	0,														// 0x0000_0070
	0,														// 0x0000_0074
	0,														// 0x0000_0078
	0,														// 0x0000_007C
	0,														// 0x0000_0080
	0,														// 0x0000_0084
	ADC1_2_IRQHandler,										// 0x0000_0088
	0,														// 0x0000_008C
	0,														// 0x0000_0090
	0,														// 0x0000_0094
	0,														// 0x0000_0098
	0,														// 0x0000_009C
	0,														// 0x0000_00A0
	0,														// 0x0000_00A4
	0,														// 0x0000_00A8
	0,														// 0x0000_00AC
	0,														// 0x0000_00B0 TIM2
	0,														// 0x0000_00B4
	0,														// 0x0000_00B8
	0,														// 0x0000_00BC
	0,														// 0x0000_00C0
	0,														// 0x0000_00C4
	0,														// 0x0000_00C8
	0,														// 0x0000_00CC
	0,														// 0x0000_00D0
	0,														// 0x0000_00D4 USART1
	0,														// 0x0000_00D8
	0,														// 0x0000_00DC
};


int main(void)
{
	// ========================================
	// Configuración de reloj: 72MHz vía PLL
	// ========================================
	DEVMAP->RCC.REGs.CR |= (1 << 16);              // Habilitar HSE (8MHz)
	while (!(DEVMAP->RCC.REGs.CR & (1 << 17)));    // Esperar HSE ready
	
	DEVMAP->RCC.REGs.CR &= ~(1 << 24);             // Deshabilitar PLL
	DEVMAP->RCC.REGs.CFGR |= (0b0111 << 18);       // PLLMUL = 9 (8MHz * 9 = 72MHz)
	DEVMAP->RCC.REGs.CFGR |= (1 << 16);            // PLLSRC = HSE
	DEVMAP->RCC.REGs.CR |= (1 << 24);              // Habilitar PLL
	while (!(DEVMAP->RCC.REGs.CR & (1 << 25)));    // Esperar PLL ready
	
	DEVMAP->FLASH.REGs.ACR |= (0b010 << 0);        // FLASH: 2 wait states
        DEVMAP->RCC.REGs.CFGR |= (0b100 << 8);         // APB1: /2 (36MHz)
	
	DEVMAP->RCC.REGs.CFGR |= (0b10 << 0);          // SW = PLL
	while (!(DEVMAP->RCC.REGs.CFGR & (0b10 << 2))); // Esperar conmutación
	
        // ========================================
        // Habilitar relojes periféricos
        // ========================================
        DEVMAP->RCC.REGs.APB1ENR |= (1 << 0);  // TIM2 clock enable
        DEVMAP->RCC.REGs.APB2ENR |= (1 << 2);  // GPIOA clock enable
        DEVMAP->RCC.REGs.APB2ENR |= (1 << 3);  // GPIOB clock enable
        DEVMAP->RCC.REGs.APB2ENR |= (1 << 9);  // ADC1 clock enable
        DEVMAP->RCC.REGs.APB2ENR |= (1 << 0);  // AFIO clock enable
	
	// ========================================
	// Deshabilitar JTAG para liberar PA15
	// ========================================
	// AFIO->MAPR: SWJ_CFG = 010 (JTAG-DP Disabled, SW-DP Enabled)
	// Esto libera PA15, PB3, PB4 pero mantiene PA13 (SWDIO) y PA14 (SWCLK)
	uint32_t *AFIO_MAPR = (uint32_t*)(0x40010000 + 0x04);  // AFIO base + offset MAPR
        *AFIO_MAPR &= ~(0b111 << 24);  // Limpiar bits SWJ_CFG[26:24]
        *AFIO_MAPR |=  (0b010 << 24);  // SWJ_CFG = 010 (Deshabilitar JTAG, mantener SWD)

        // ========================================
        // Configurar PB1 como entrada analógica (ADC1_IN9)
        // ========================================
        DEVMAP->GPIOs[GPIOB].REGs.CRL &= ~((uint32_t)0xF << 4);

        // ========================================
        // Configurar TIM2 como contador libre para time-stamping
        // ========================================
        DEVMAP->TIMs[TIM2].REGs.CR1 = 0;
        DEVMAP->TIMs[TIM2].REGs.PSC = TIM2_PRESCALER_30KHZ;            // 72MHz / 2400 = 30kHz -> 33.33us por tick
        DEVMAP->TIMs[TIM2].REGs.ARR = TIM2_AUTO_RELOAD_MAX_16BIT;      // Conteo libre de 16 bits
        DEVMAP->TIMs[TIM2].REGs.CNT = 0;
        DEVMAP->TIMs[TIM2].REGs.CR1 |= (1 << 0);             // CEN: habilitar contador

        // ========================================
        // Configurar ADC1 para lecturas continuas en canal 9 (PB1)
        // ========================================
        // El ADC1 necesita un reloj máximo de 14MHz, así que dividimos PCLK2 (72MHz) / 8 = 9MHz
        DEVMAP->RCC.REGs.CFGR &= ~(0b11 << 14);
        DEVMAP->RCC.REGs.CFGR |=  (0b11 << 14);             // ADCPRE = 10: PCLK2/8

        // Configurar ADC primero, ANTES de encender
        DEVMAP->ADC[ADC1].REGs.SMPR2 &= ~(0b111 << (3 * ADC_CHANNEL_B1));
        DEVMAP->ADC[ADC1].REGs.SMPR2 |=  (ADC_SAMPLE_TIME_CYCLES << (3 * ADC_CHANNEL_B1)); // Sample time = 239.5 ciclos
        DEVMAP->ADC[ADC1].REGs.SQR1 &= ~(0b1111 << 20);      // Longitud de secuencia = 1
        DEVMAP->ADC[ADC1].REGs.SQR3  = ADC_CHANNEL_B1;       // Canal 9 (PB1) como primera conversión
        DEVMAP->ADC[ADC1].REGs.CR2  |= (1 << 1);             // Modo continuo habilitado
        
        // Ahora encender y calibrar
        DEVMAP->ADC[ADC1].REGs.CR2  |= (1 << 0);             // ADON: Encender ADC (primera vez)
        for(volatile int i=0; i<1000; i++);                  // Delay para estabilización
        
        DEVMAP->ADC[ADC1].REGs.CR2  |= (1 << 3);             // RSTCAL: Reset calibration
        while (DEVMAP->ADC[ADC1].REGs.CR2 & (1 << 3));       // Esperar que se complete reset
        
        DEVMAP->ADC[ADC1].REGs.CR2  |= (1 << 2);             // CAL: Iniciar calibración
        while (DEVMAP->ADC[ADC1].REGs.CR2 & (1 << 2));       // Esperar que se complete calibración
        
        // Arranque determinista de conversión continua por software
        DEVMAP->ADC[ADC1].REGs.CR2 &= ~(0b111 << 17);        // EXTSEL = 111 (SWSTART)
        DEVMAP->ADC[ADC1].REGs.CR2 |=  (0b111 << 17);
        DEVMAP->ADC[ADC1].REGs.CR2 |= (1 << 20);             // EXTTRIG habilitado

        // Segunda escritura a ADON inicia la conversión en modo continuo
        DEVMAP->ADC[ADC1].REGs.CR2  |= (1 << 0);             // ADON: Iniciar conversión continua
        DEVMAP->ADC[ADC1].REGs.CR2 |= (1 << 22);             // SWSTART: disparar conversión
        // ========================================
        // Configurar PA[15:0] como salidas 50MHz push-pull
        // ========================================
		// CRL configura PA[7:0]:   MODE=11 (50MHz), CNF=00 (Push-pull) = 0x3 por pin
		// CRH configura PA[15:8]:  MODE=11 (50MHz), CNF=00 (Push-pull) = 0x3 por pin
        DEVMAP->GPIOs[GPIOA].REGs.CRL = GPIO_OUTPUT_MODE_PUSH_PULL;  // PA[7:0]  como salidas
        DEVMAP->GPIOs[GPIOA].REGs.CRH = GPIO_OUTPUT_MODE_PUSH_PULL;  // PA[15:8] como salidas
	
        // ========================================
        // Bucle principal: encender LEDs en secuencia
        // ========================================
        // Preparar estado inicial del comparador de umbral
        // Descartar la primera muestra tras el arranque para evitar lecturas iniciales incorrectas
        while (!(DEVMAP->ADC[ADC1].REGs.SR & (1 << 1)));
        (void)(DEVMAP->ADC[ADC1].REGs.DR & 0xFFFF);

        // Preparar estado inicial del comparador de umbral con la siguiente conversión válida
        while (!(DEVMAP->ADC[ADC1].REGs.SR & (1 << 1)));
        uint16_t initial_sample = (uint16_t)(DEVMAP->ADC[ADC1].REGs.DR & 0xFFFF);
        low_detected = (initial_sample < ADC_THRESHOLD_LOW_RAW);


        // Habilitar interrupción de fin de conversión
        DEVMAP->ADC[ADC1].REGs.CR1 |= (1 << 5);             // EOCIE
        ENA_IRQ(IRQ_ADC1_2);


        for(;;) {
            DEVMAP->GPIOs[GPIOA].REGs.ODR = led_pattern[((DEVMAP->TIMs[TIM2].REGs.CNT  / delta_ticks)+(laps)) % LED_PATTERN_LENGTH];
        }

        return 0;
}

void ADC1_2_IRQHandler(void)
{
        // Leer DR (esto automáticamente limpia EOC en modo continuo)
    uint16_t sample = (uint16_t)(DEVMAP->ADC[ADC1].REGs.DR & 0xFFFF);

    if (!low_detected && (sample < ADC_THRESHOLD_LOW_RAW)) {
        low_detected = 1;
    }

    if (low_detected && (sample > ADC_THRESHOLD_HIGH_RAW)) {
            uint32_t ticks_one_lap = DEVMAP->TIMs[TIM2].REGs.CNT;
			DEVMAP->TIMs[TIM2].REGs.CNT = 0;
            delta_ticks = ticks_one_lap / LED_PATTERN_LENGTH; // Ventana de 2 grados
            if (delta_ticks <= 0) {
                    delta_ticks = 1;
            }
            low_detected = 0;
			laps = (laps + 1) % 180;
    }
	DEVMAP->ADC[ADC1].REGs.SR &= ~(1 << 1);					// Clear EOC bit
	CLR_IRQ(IRQ_ADC1_2);
}

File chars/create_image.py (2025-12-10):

from PIL import Image


def bmp_to_led_pattern(image_path):
    """
    Convierte una imagen BMP de 14x180 a un vector de uint16_t para C.

    Mapeo de filas a pines físicos de GPIOA:
    - Fila 0 (superior) -> led_pins[0] = PA7  -> bit 7 del ODR
    - Fila 1            -> led_pins[1] = PA6  -> bit 6 del ODR
    - Fila 2            -> led_pins[2] = PA5  -> bit 5 del ODR
    - Fila 3            -> led_pins[3] = PA4  -> bit 4 del ODR
    - Fila 4            -> led_pins[4] = PA3  -> bit 3 del ODR
    - Fila 5            -> led_pins[5] = PA2  -> bit 2 del ODR
    - Fila 6            -> led_pins[6] = PA1  -> bit 1 del ODR
    - Fila 7            -> led_pins[7] = PA0  -> bit 0 del ODR
    - Fila 8            -> led_pins[8] = PA8  -> bit 8 del ODR
    - Fila 9            -> led_pins[9] = PA9  -> bit 9 del ODR
    - Fila 10           -> led_pins[10] = PA10 -> bit 10 del ODR
    - Fila 11           -> led_pins[11] = PA11 -> bit 11 del ODR
    - Fila 12           -> led_pins[12] = PA12 -> bit 12 del ODR
    - Fila 13 (inferior)-> led_pins[13] = PA15 -> bit 15 del ODR

    Cada columna (180 total) es un elemento del vector.
    Pixel negro (oscuro) = bit en 1 (LED encendido)
    Pixel blanco (claro) = bit en 0 (LED apagado)
    """

    # Array de mapeo: led_pins[i] indica el bit del ODR para la fila i
    led_pins = [7, 6, 5, 4, 3, 2, 1, 0, 8, 9, 10, 11, 12, 15]

    try:
        img = Image.open(image_path)

        # Verificar dimensiones
        width, height = img.size
        if width != 180 or height != 14:
            print(f"Error: La imagen debe ser 180x14 pixels, pero es {width}x{height}")
            return

        # Convertir a escala de grises para facilitar procesamiento
        img = img.convert("L")
        pixels = img.load()

        # Generar el vector
        pattern = []

        for col in range(180):  # 180 columnas (ángulos)
            value = 0
            for row in range(14):  # 14 filas (LEDs)
                # Leer pixel: si es OSCURO (<128) -> bit = 1 (LED encendido)
                pixel_value = pixels[col, row]
                if pixel_value < 128:  # Umbral para negro
                    # Mapear fila de imagen -> bit del ODR según led_pins[]
                    odr_bit = led_pins[row]
                    value |= 1 << odr_bit

            pattern.append(value)

        # Formatear salida como código C
        print("static const uint16_t led_pattern[180] = {")

        for i in range(0, len(pattern), 8):
            chunk = pattern[i : i + 8]
            formatted = ", ".join(f"0x{val:04X}" for val in chunk)
            if i + 8 < len(pattern):
                print(f"\t{formatted},")
            else:
                print(f"\t{formatted}")

        print("};")

        # Información adicional
        print(f"\n// Total de patrones generados: {len(pattern)}")
        print(f"// Cada patrón representa una columna de la imagen (posición angular)")
        print(f"// Bits encendidos (1) = LEDs encendidos (píxeles negros en la imagen)")
        print(f"// Ejemplo: 0x8080 = bits 7 y 15 activos = PA7 y PA15 encendidos")

    except FileNotFoundError:
        print(f"Error: No se encontró el archivo '{image_path}'")
        print(
            "Asegúrate de que 'image.bmp' esté en el mismo directorio que este script."
        )
    except Exception as e:
        print(f"Error al procesar la imagen: {e}")


if __name__ == "__main__":
    bmp_to_led_pattern("image.bmp")

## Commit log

2025-11-19 update component list spreadsheet
    [comp_list.xlsx]
2025-12-06 push 3d and first source
    [Part1.ipt, Propeller.PrjPcb, cnc_wood_holder.ipt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]
2025-12-06 Configure ADC-driven LED sequencing
2025-12-07 Fix ADC setup for continuous sampling
    [main.c]
2025-12-07 Improve ADC startup flow
2025-12-07 Add ADC and USART example implementation
    - Introduced adc_example.c with a complete example for ADC and USART communication.
    - Implemented interrupt handlers for ADC and USART.
    - Configured system clock and peripheral clocks for ADC and USART.
    - Added GPIO configuration for ADC input and USART TX/RX.
    - Implemented a state machine to handle ADC readings and transmit data via USART.
    - Included vector table for interrupt handling.
2025-12-07 Add hysteresis thresholds for LED advance
2025-12-10 Add interrupt-based threshold timing and speed computation
2025-12-10 Add LED pattern control and GPIO output function
    - Introduced a new LED pattern array for controlling LED sequences.
    - Implemented `set_gpioa_odr_from_mask` function to set GPIOA output data register based on a 16-bit mask.
    - Updated the main loop to utilize the new LED pattern and GPIO function for LED control.
    - Removed redundant code related to LED index management and ADC handling.
    - Adjusted interrupt handler to improve LED control logic based on ADC readings.
2025-12-10 Fix formatting in main function for better readability
    [main.c]
2025-12-10 Add BMP image processing script and LED pattern generation
2025-12-10 Refactor voltage detection logic to use raw ADC sample values instead of calculated millivolts
2025-12-11 Refactor timer setup and thresholds
2025-12-11 Refactor ADC interrupt handler to optimize lap tracking and remove moving average logic; update related variables and calculations for improved performance.
2025-12-11 Add smoothing filter to lap timing
2025-12-11 Refactor code structure for improved readability and maintainability
    [Propeller.PrjPcb, pcb_propeller.PcbDoc, sch_propeller.SchDoc]
